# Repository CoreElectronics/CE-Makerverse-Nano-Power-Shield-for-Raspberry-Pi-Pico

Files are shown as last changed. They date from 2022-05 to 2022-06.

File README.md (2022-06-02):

# Makerverse™ Nano Power Timer HAT for Raspberry Pi Pico

This is the repo for the Core Electronics [Makerverse Nano Power Timer HAT for Raspberry Pi Pico](https://core-electronics.com.au/catalog/product/view/sku/ce08492).

The PCB layout project requires KiCAD 6.0 or newer to view. The schematic is provided in PDF format in the Documents folder.

## License
This project is open source - please review the LICENSE.md file for further licensing information.

If you have any technical questions, or concerns about licensing, please contact technical support on the [Core Electronics forums](https://forum.core-electronics.com.au/).

*\"PiicoDev\" and the PiicoDev logo are trademarks of Core Electronics Pty Ltd.*

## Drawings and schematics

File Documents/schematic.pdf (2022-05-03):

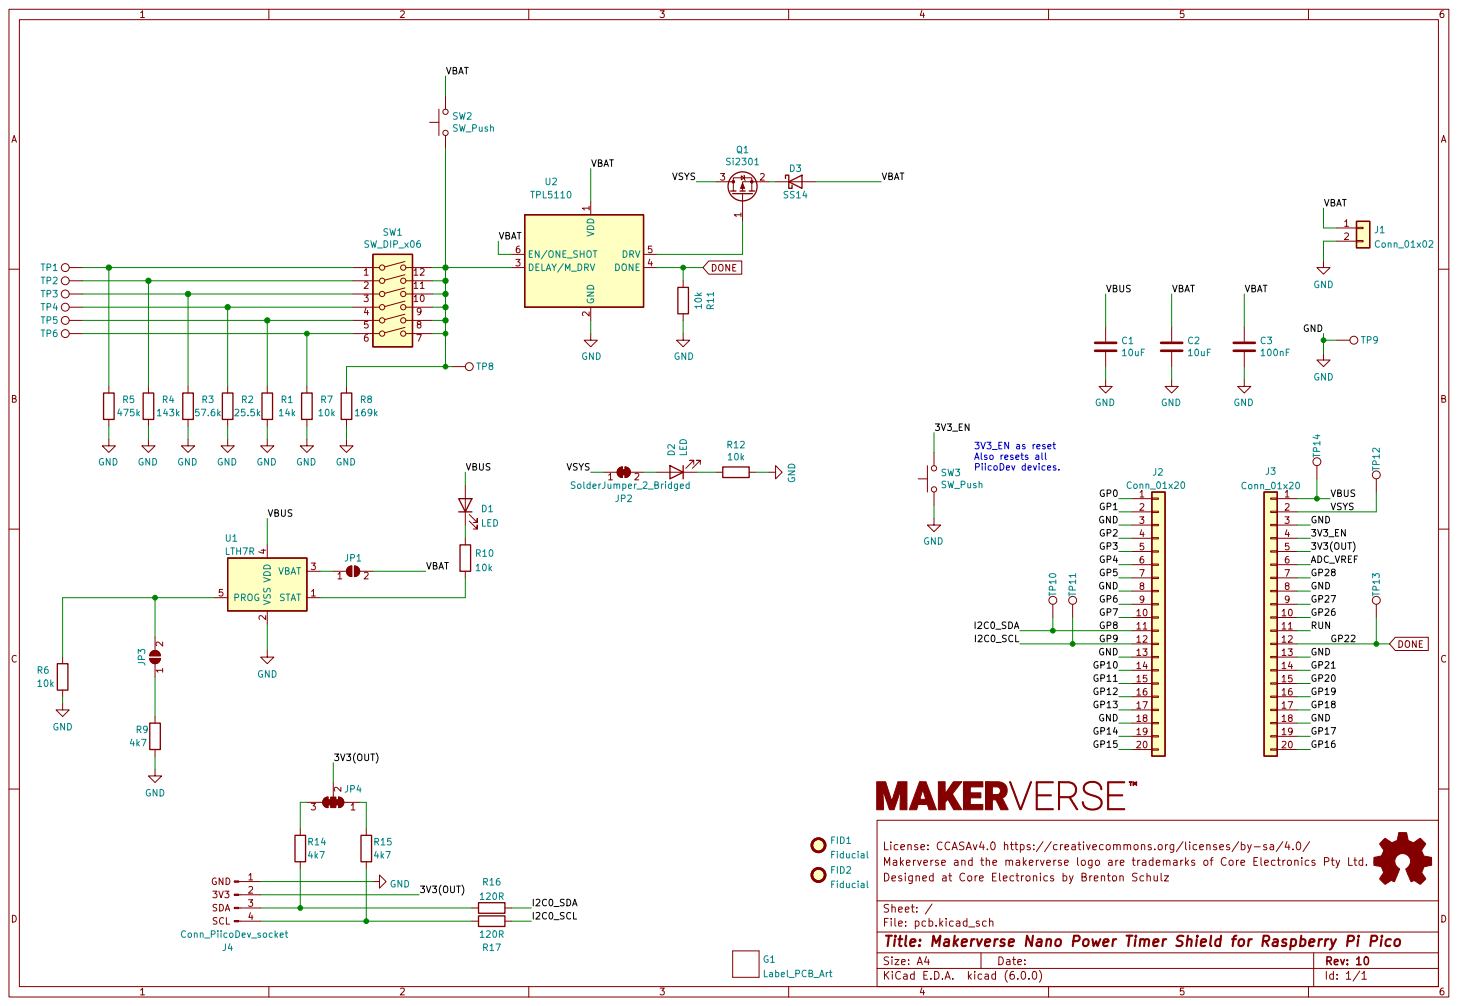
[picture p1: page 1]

2 DELAY/M_DRV 3 DONE 4 DRV 5 EN/ONE_SHOT 6 U2 TPL5110 TP2 TP4 TP6 TP1 TP5 TP3

3V3_EN as reset Also resets all PiicoDev devices.

License: CCASAv4.0 https://creativecommons.org/licenses/by-sa/4.0/ GND

Makerverse and the makerverse logo are trademarks of Core Electronics Pty Ltd.
File: pcb.kicad_sch Sheet: / Designed at Core Electronics by Brenton Schulz

Id: 1/1 Title: Makerverse Nano Power Timer Shield for Raspberry Pi Pico

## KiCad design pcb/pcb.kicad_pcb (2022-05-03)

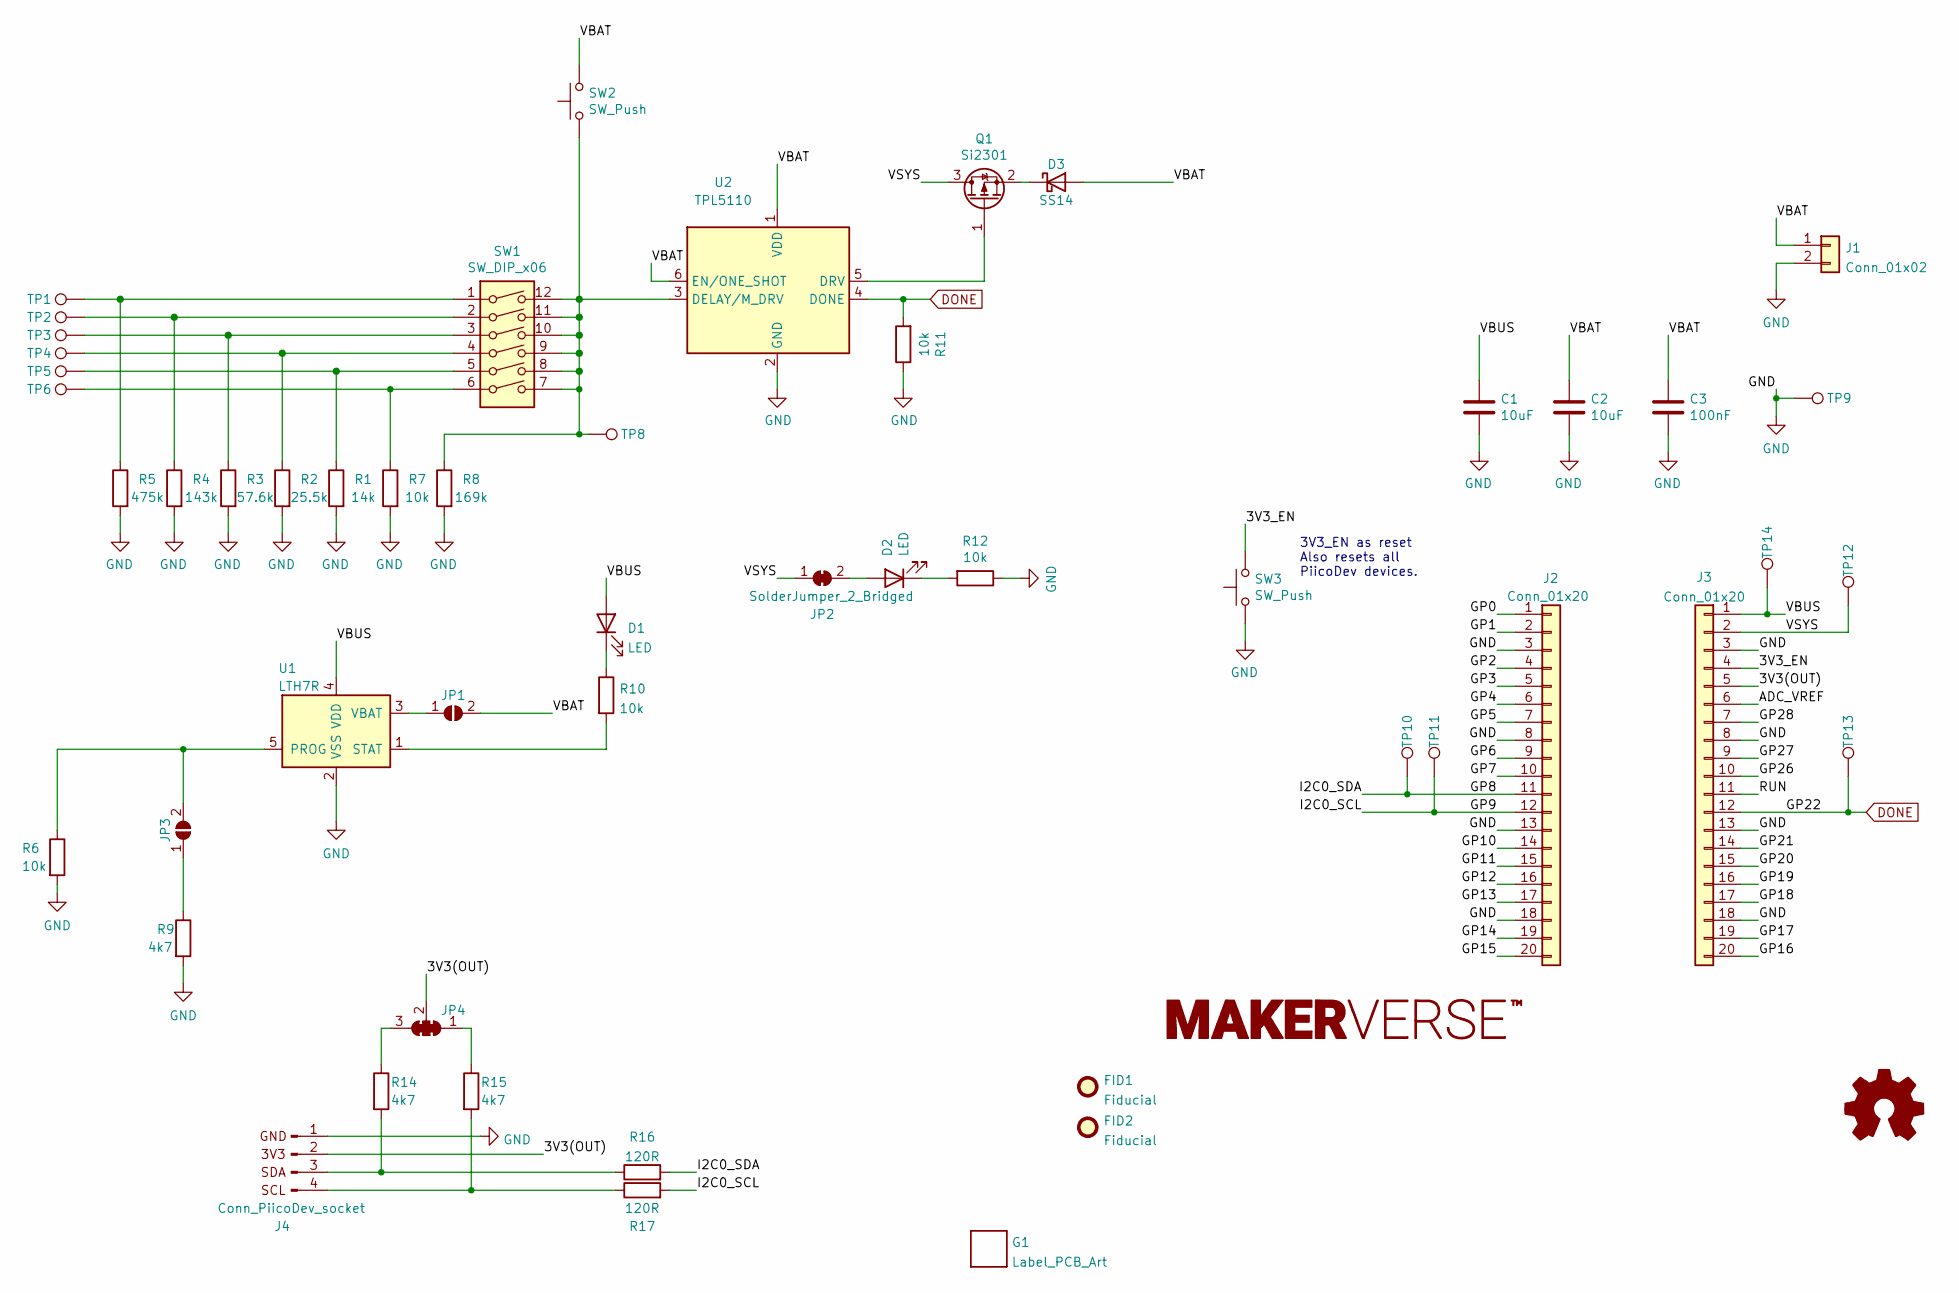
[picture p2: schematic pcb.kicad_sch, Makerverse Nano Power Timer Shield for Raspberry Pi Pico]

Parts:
C1, C2: 10uF; C_0603_1608Metric
C3: 100nF; C_0402_1005Metric
D1, D2: LED; LED_0603_1608Metric
D3: SS14; D_SMA
FID1, FID2: Fiducial; Fiducial_1mm_Mask2mm
G1: Label_PCB_Art; CE08492
G2: LOGO_Makerverse; makerverse_logo_short_14.0x2.4mm
J1: Conn_01x02; JST_PH_S2B-PH-SM4-TB_1x02-1MP_P2.00mm_Horizontal
J2, J3: Conn_01x20; PinSocket_1x20_P2.54mm_Vertical-Large-Pads
J4: Conn_PiicoDev_socket; JST_SH_SM04B-SRSS-TB_1x04-1MP_P1.00mm_Horizontal
JP1, JP3: SolderJumper_2_Open; SolderJumper-2_P1.3mm_Open_RoundedPad1.0x1.5mm
JP2: SolderJumper_2_Bridged; SolderJumper-2_P1.3mm_Bridged_RoundedPad1.0x1.5mm
JP4: SolderJumper_3_Bridged123; SolderJumper-3_P1.3mm_Closed_RoundedPad1.0x1.5mm_NumberLabe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
Q1: Si2301; SOT-23
R1: 14k; R_0402_1005Metric
R2: 25.5k; R_0402_1005Metric
R3: 57.6k; R_0402_1005Metric
R4: 143k; R_0402_1005Metric
R5: 475k; R_0402_1005Metric
R6, R7, R10, R11, R12: 10k; R_0402_1005Metric
R8: 169k; R_0402_1005Metric
R9, R14, R15: 4k7; R_0402_1005Metric
R16, R17: 120R; R_0402_1005Metric
SW1: SW_DIP_x06; SW_DIP_SPSTx06_Slide_6.7x16.8mm_W8.61mm_P2.54mm_LowProfile
SW2, SW3: SW_Push; SW_Tactile_5x5
TP1, TP2, TP3, TP4, TP5, TP6, TP8, TP9, TP10, TP11, TP12, TP13, TP14: TestPoint; TestPoint_Pad_D1.5mm
U1: LTH7R; SOT-23-5
U2: TPL5110; SOT-23-6

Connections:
/3V3(OUT): J3.5, J4.2, JP4.2 (C)
/3V3_EN: J3.4, SW3.2
/ADC_VREF: J3.6
/GP0: J2.1
/GP1: J2.2
/GP2: J2.4
/GP3: J2.5
/GP4: J2.6
/GP5: J2.7
/GP6: J2.9
/GP7: J2.10
/GP8: J2.11, R16.2, TP10.1
/GP9: J2.12, R17.2, TP11.1
/GP10: J2.14
/GP11: J2.15
/GP12: J2.16
/GP13: J2.17
/GP14: J2.19
/GP15: J2.20
/GP16: J3.20
/GP17: J3.19
/GP18: J3.17
/GP19: J3.16
/GP20: J3.15
/GP21: J3.14
/GP26: J3.10
/GP27: J3.9
/GP28: J3.7
/RUN: J3.11
/VBAT: C2.1, C3.1, D3.2 (A), J1.1, JP1.2 (B), SW2.2, U2.1 (VDD), U2.6 (EN/ONE_SHOT)
/VBUS: C1.1, D1.2 (A), J3.1, TP14.1, U1.4 (VDD)
/VSYS: J3.2, JP2.1 (A), Q1.3 (D), TP12.1
DONE: J3.12, R11.2, TP13.1, U2.4 (DONE)
GND: C1.2, C2.2, C3.2, J1.2, J2.3, J2.8, J2.13, J2.18, J3.3, J3.8, J3.13, J3.18, J4.1, R1.2, R2.2, R3.2, R4.2, R5.2, R6.2, R7.2, R8.2, R9.2, R11.1, R12.1, SW3.1, TP9.1, U1.2 (VSS), U2.2 (GND)
unnamed: D1.1 (K), R10.1
unnamed: D2.1 (K), R12.2
unnamed: D2.2 (A), JP2.2 (B)
unnamed: D3.1 (K), Q1.2 (S)
unnamed: J4.3, R14.2, R16.1
unnamed: J4.4, R15.2, R17.1
unnamed: JP1.1 (A), U1.3 (VBAT)
unnamed: JP3.1 (A), R9.1
unnamed: JP3.2 (B), R6.1, U1.5 (PROG)
unnamed: JP4.1 (A), R15.1
unnamed: JP4.3 (B), R14.1
unnamed: Q1.1 (G), U2.5 (DRV)
unnamed: R1.1, SW1.5, TP5.1
unnamed: R2.1, SW1.4, TP4.1
unnamed: R3.1, SW1.3, TP3.1
unnamed: R4.1, SW1.2, TP2.1
unnamed: R5.1, SW1.1, TP1.1
unnamed: R7.1, SW1.6, TP6.1
unnamed: R8.1, SW1.7, SW1.8, SW1.9, SW1.10, SW1.11, SW1.12, SW2.1, TP8.1, U2.3 (DELAY/M_DRV)
unnamed: R10.2, U1.1 (STAT)

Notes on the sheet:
3V3_EN as reset Also resets all PiicoDev devices.

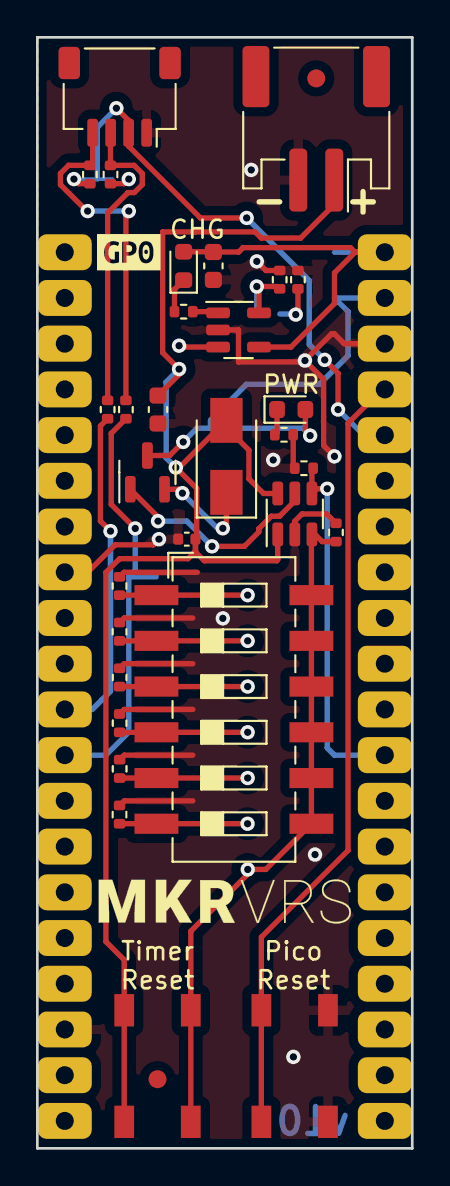
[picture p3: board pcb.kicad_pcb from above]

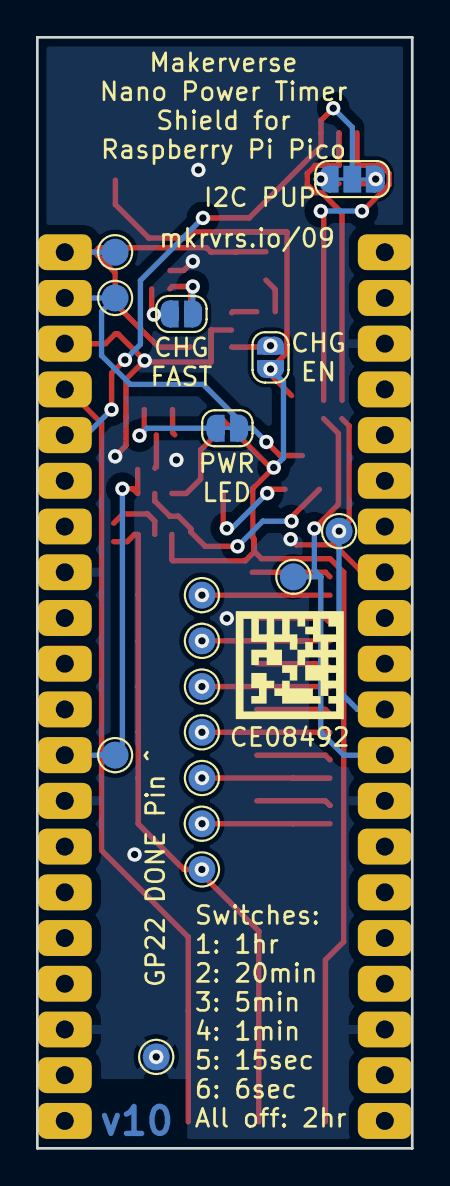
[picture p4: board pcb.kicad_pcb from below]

Board: 2 copper layers, 20.8 x 61.7 mm, 54 parts (18 on the bottom side), 29 nets.

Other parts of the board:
kibuzzard-624E6047: G***; kibuzzard-624E6047
